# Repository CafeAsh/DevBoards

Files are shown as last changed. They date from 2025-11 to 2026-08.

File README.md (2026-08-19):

# Embedded Hardware Design Library

A collection of reusable embedded hardware designs developed as a personal reference library for future electronics and embedded-systems projects.

This repository contains custom development boards, microcontroller platforms, and DC-DC power-conversion designs. The goal is to maintain a structured library of proven circuit designs that can be reused, adapted, and expanded for future projects.

The designs emphasize **practical PCB implementation, component selection, power integrity, signal integrity, manufacturability, and reusable hardware architecture**.

This repository also serves as an ongoing engineering and learning platform. Designs are developed, evaluated, and refined to strengthen practical skills in embedded systems, PCB design, power electronics, signal integrity, and hardware validation. Lessons learned from each design are incorporated into subsequent revisions and projects.

---

## Repository Contents

### Microcontroller Development Boards

| Platform | MCU | Primary Focus |
| --- | --- | --- |
| ATtiny1616 | Microchip ATtiny1616 | Low-cost / low-power embedded control |
| ATmega32U4 | Microchip ATmega32U4 | USB-capable embedded applications |
| ESP32-S3 | Espressif ESP32-S3 | Wi-Fi / Bluetooth / high-performance embedded applications |
| RP2040 | Raspberry Pi RP2040 | Dual-core MCU development |
| STM32F103C8T6 | STMicroelectronics STM32F103C8T6 | ARM Cortex-M3 embedded development |

### Power Electronics

The repository also contains several DC-DC converter reference designs:

* Buck converter
* Boost converter
* SEPIC converter

These designs are intended as reusable starting points for future power-supply requirements, with component values and operating parameters selected for their respective target applications.

---

## Design Philosophy

The primary objective of this repository is **reusability**.

Rather than designing every development board or power stage from scratch, commonly used circuits are maintained as modular reference designs that can be incorporated into future projects.

Designs are developed with consideration for:

* Component availability
* PCB manufacturability
* Power distribution
* Decoupling and bypassing
* Signal integrity
* Grounding and return paths
* Programming and debugging interfaces
* Protection circuitry
* Ease of modification and reuse

---

## Development Boards

### ATtiny1616

Reference development board centered around the Microchip ATtiny1616 microcontroller.

Design considerations include:

* USB-to-serial conversion
* Programming/debug interface
* GPIO accessibility
* External power input
* Reset/programming provisions

### ATmega32U4

USB-capable development board based on the ATmega32U4.

The design provides a reusable platform for projects requiring:

* Native USB
* GPIO expansion
* Embedded control
* HID applications
* External peripherals

### ESP32-S3

Development platform based on the ESP32-S3 for projects requiring greater processing capability and wireless connectivity.

The design focuses on providing a reusable hardware platform while accounting for the additional power, RF, and high-speed considerations associated with the device.

### RP2040

Development board based on the Raspberry Pi RP2040.

The design provides a flexible platform for embedded applications requiring:

* Dual-core processing
* High-speed GPIO
* Programmable I/O
* USB connectivity
* External peripheral interfaces

### STM32F103C8T6

ARM Cortex-M3 development platform based on the STM32F103C8T6.

The design provides a compact reference platform for applications requiring:

* ARM Cortex-M development
* General-purpose peripherals
* Multiple communication interfaces
* External debugging/programming

---

## Power Conversion

### Buck Converter

Step-down DC-DC converter designs for applications requiring a regulated output voltage below the input voltage.

Design considerations include:

* Switching frequency
* Inductor selection
* Output capacitance
* MOSFET selection
* Diode or synchronous rectification
* Feedback network
* Switching losses
* Thermal performance
* PCB current paths

### Boost Converter

Step-up DC-DC converter designs for generating an output voltage greater than the input voltage.

Key considerations include:

* Inductor selection
* Switching device selection
* Diode characteristics
* Output ripple
* Duty-cycle limitations
* Feedback and regulation
* Current requirements

### SEPIC Converter

Single-Ended Primary-Inductor Converter designs for applications requiring an output voltage that may be either above or below the input voltage.

SEPIC designs are particularly useful when the input voltage can cross the desired output voltage while maintaining a non-inverting regulated output.

---

## Design Documentation

Each design is intended to become increasingly self-documenting as the repository develops.

Where applicable, documentation will include:

* Design objectives
* Electrical specifications
* Schematic
* PCB layout
* Bill of materials
* Component selection rationale
* Design calculations
* Simulation results
* PCB fabrication files
* Assembly information
* Bring-up and validation notes
* Known limitations
* Revision history

Measured results will be distinguished from simulated or calculated values.

---

## Tools

The designs in this repository may utilize:

* **KiCad** — Schematic capture and PCB design
* **LTspice** — Circuit simulation
* **Datasheet analysis** — Component selection and electrical verification
* **Embedded development tools** — Firmware development and hardware bring-up

Additional tools may be added as the library expands.

---

## Future Development

Planned additions and improvements include:

* Additional MCU development boards
* Expanded DC-DC converter library
* Reusable power-entry circuits
* USB interface designs
* Debug/programming interfaces
* ESD and transient protection circuits
* Load-switch and power-management circuits

---

## Status

This repository is an actively evolving engineering reference library.

Designs should be considered **development/reference hardware unless explicitly marked as validated**. Electrical specifications, component selections, and layouts may change as designs are tested and refined.

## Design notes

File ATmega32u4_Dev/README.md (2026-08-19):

# ATmega32U4 Development Board

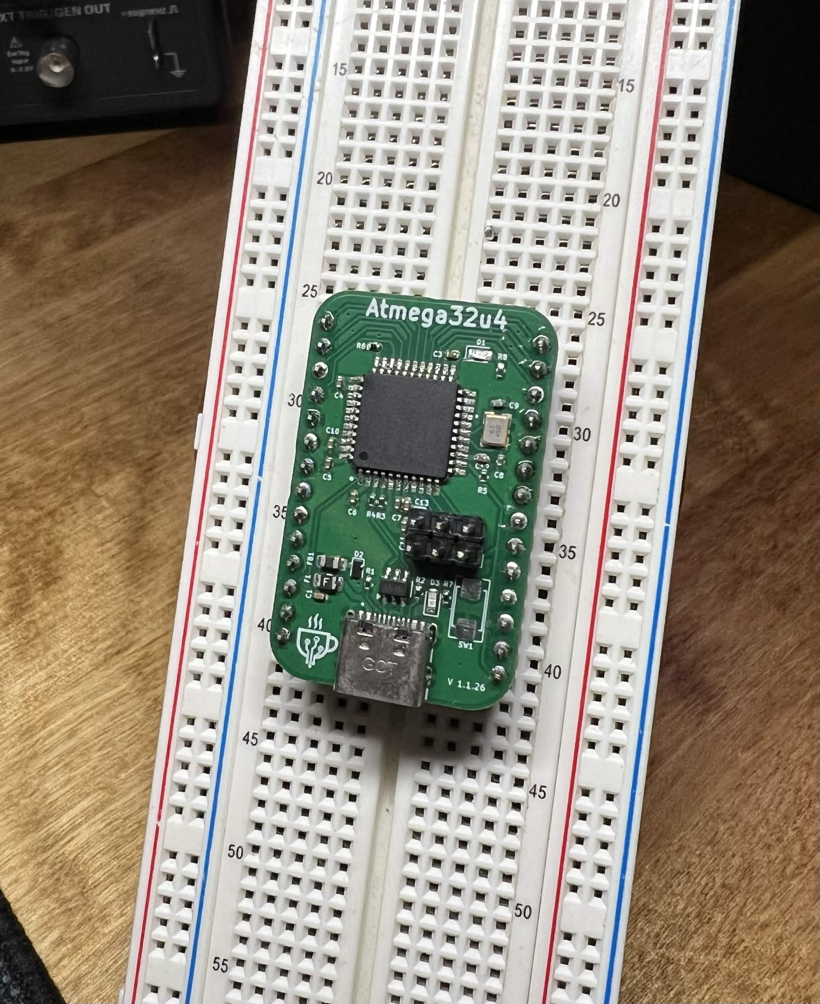
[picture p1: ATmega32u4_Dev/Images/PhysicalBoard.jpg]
Board


Development board based on the **ATmega32U4** microcontroller, designed for USB-enabled embedded projects, rapid prototyping, and firmware experimentation.

## Overview

This project provides a hardware platform built around the ATmega32U4, a microcontroller with native USB support.

Ideal use cases include:

* USB HID devices (keyboards, mice, gamepads)
* Serial communication over USB (CDC)
* Custom USB devices
* General embedded applications

## Features

* ATmega32U4 microcontroller
* Native USB support (no external USB-to-UART chip required)
* On-board 5V voltage regulation
* Power and Dataline surge protection
* ISP programming header
* Power Status LED
* Programable on board LED (Pin 13)
* GPIO breakout pins
* 16MHz Crystal Oscillator
* Designed to fit standard breadboards

## Microcontroller Details

* **Core:** AVR 8-bit
* **Flash Memory:** 32 KB
* **SRAM:** 2.5 KB
* **EEPROM:** 1 KB
* **Clock Speed:**  16 MHz
* **Interfaces:**
  * USB 2.0 Full Speed
  * UART
  * SPI
  * I2C (TWI)

## Pinout

*Pinout leaves some to be desired. Future re-works will better address pin layout*

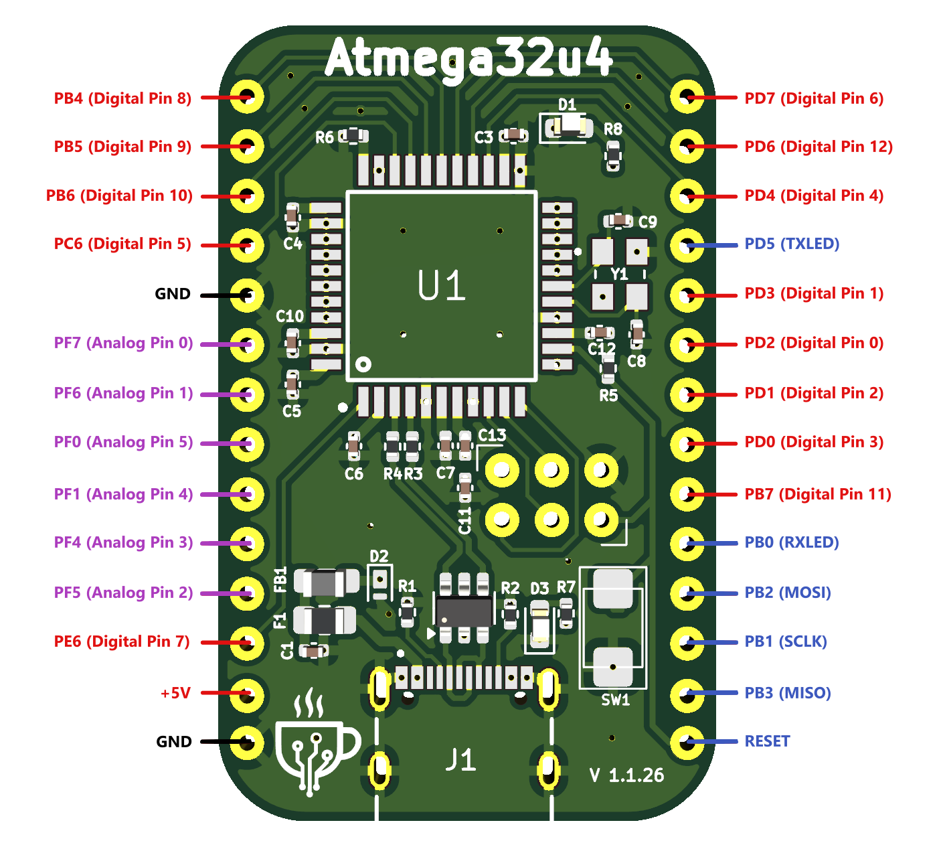
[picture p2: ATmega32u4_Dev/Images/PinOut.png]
Pinout


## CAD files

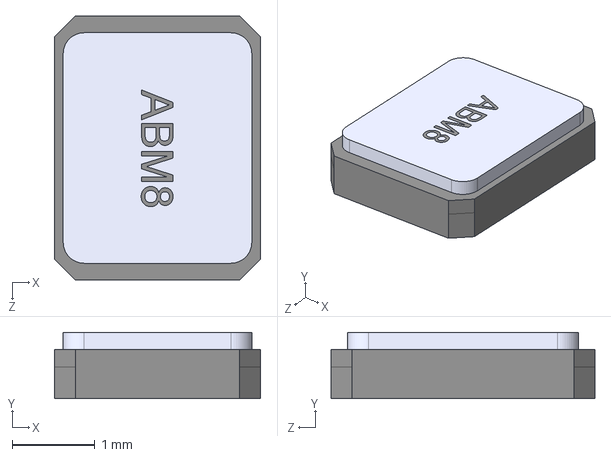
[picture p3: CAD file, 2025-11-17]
ATmega32u4_Dev 2-Layer/Models3/ABM8-16.000MHZ-10-1-U-T.step
2.50 x 0.8 x 3.20 mm

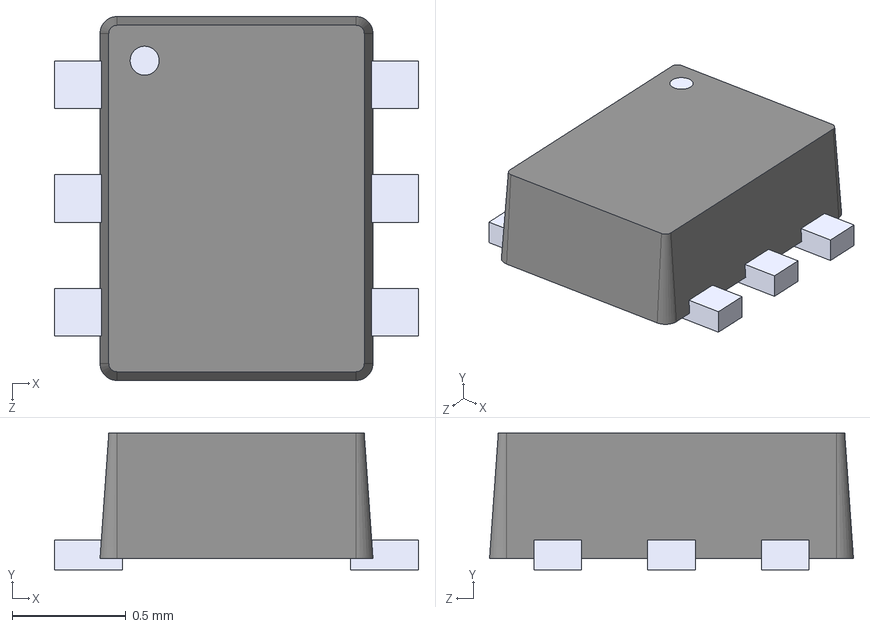
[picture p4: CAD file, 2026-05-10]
ESP32-S3_Dev/Model3/TPD2E1B06DRLR.step
1.60 x 0.6 x 1.60 mm

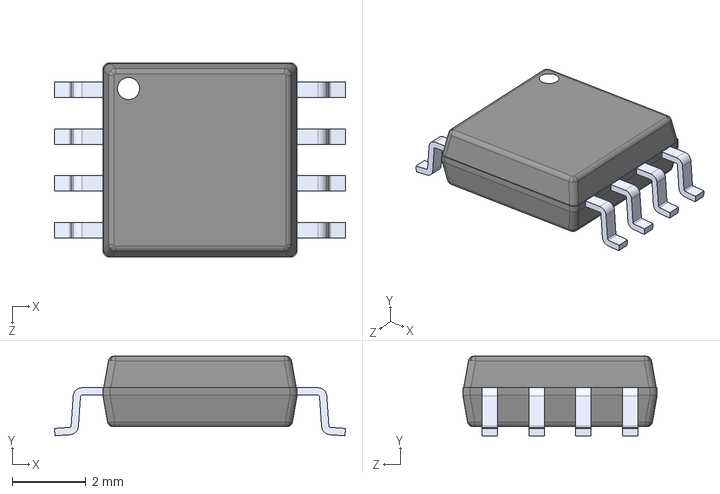
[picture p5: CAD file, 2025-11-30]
RP2040_Dev/Models3/W25Q128JVSIQ.step
7.90 x 2.16 x 5.28 mm

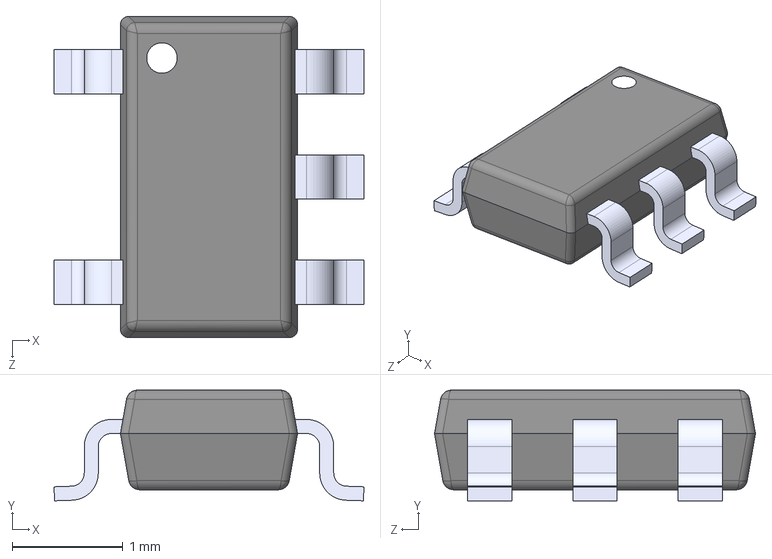
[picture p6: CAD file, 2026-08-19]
Voltage Conversion/Model3/MIC2288YD5-TR.step
2.80 x 1.00 x 2.90 mm

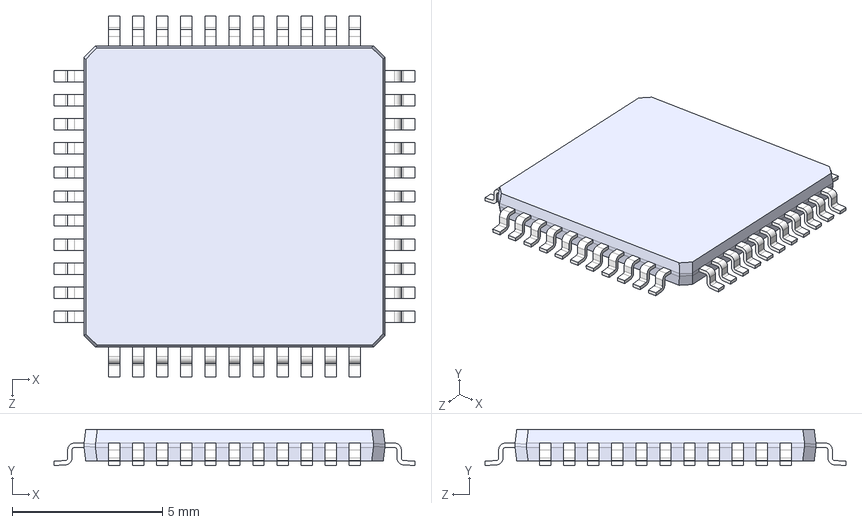
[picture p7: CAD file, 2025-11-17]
ATmega32u4_Dev 2-Layer/Models3/ATMEGA32U4-AU.step
12.0 x 1.20 x 12.0 mm

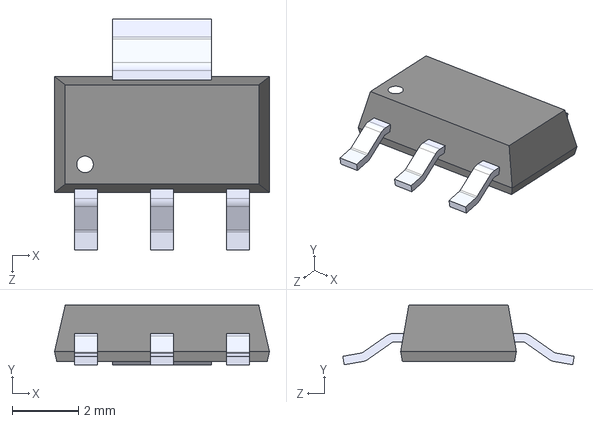
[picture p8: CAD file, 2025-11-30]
RP2040_Dev/Models3/LD1117S33TR.step
6.50 x 1.80 x 7.00 mm

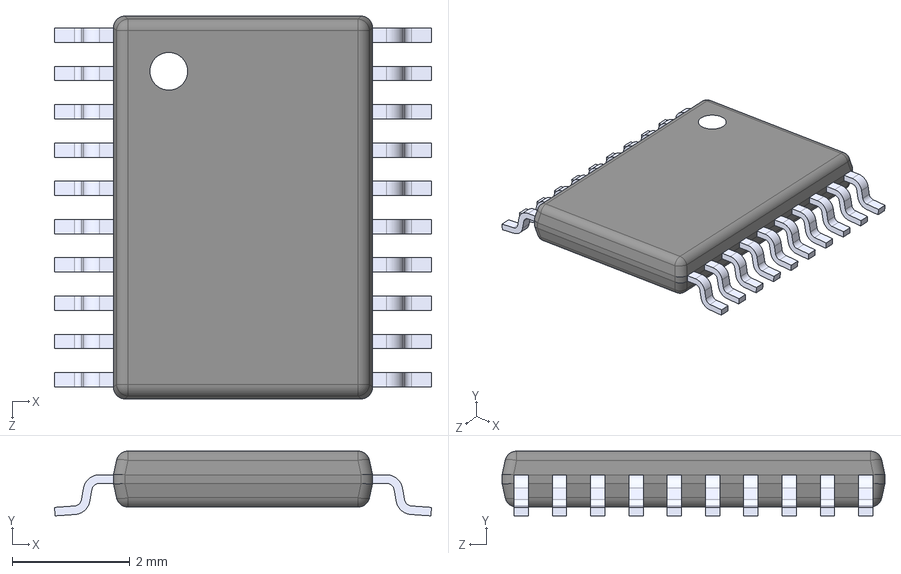
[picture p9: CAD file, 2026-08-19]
Voltage Conversion/Model3/LM5122MH_NOPB.step
6.40 x 1.10 x 6.50 mm

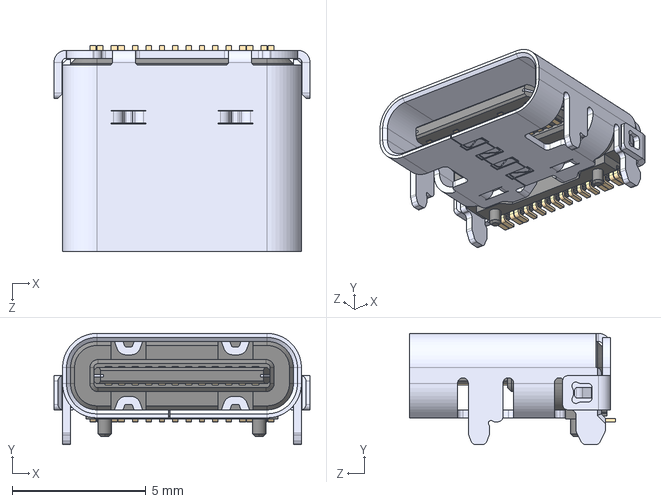
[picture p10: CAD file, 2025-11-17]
ATmega32u4_Dev 2-Layer/Models3/USB4105-GF-A.step
9.58 x 4.16 x 7.71 mm

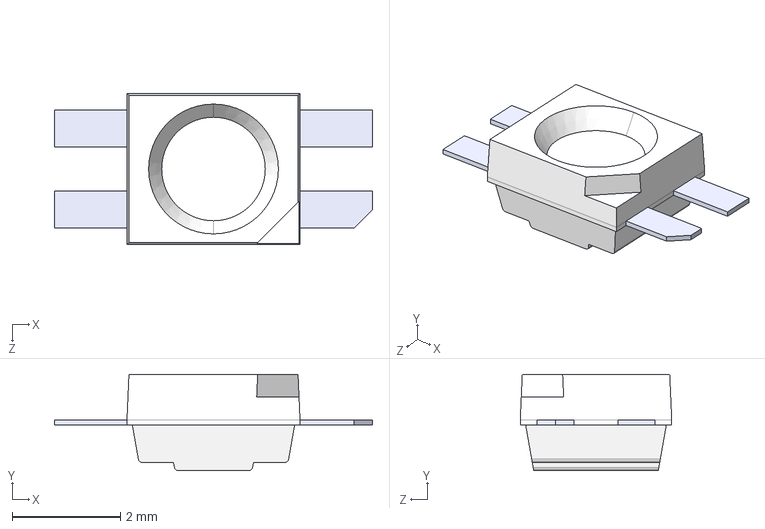
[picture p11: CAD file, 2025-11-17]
RP2040_Dev/Models3/SK6812-E.step
5.88 x 1.78 x 2.80 mm

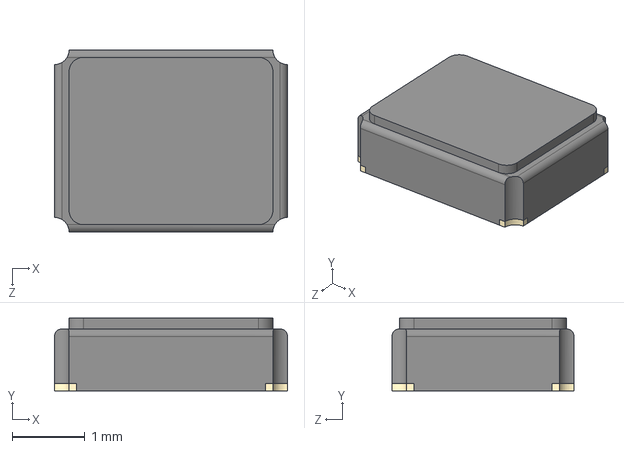
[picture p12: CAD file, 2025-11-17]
RP2040_Dev/Models3/ABM8G-12.000MHZ-4Y-T3.step
3.20 x 1.00 x 2.50 mm

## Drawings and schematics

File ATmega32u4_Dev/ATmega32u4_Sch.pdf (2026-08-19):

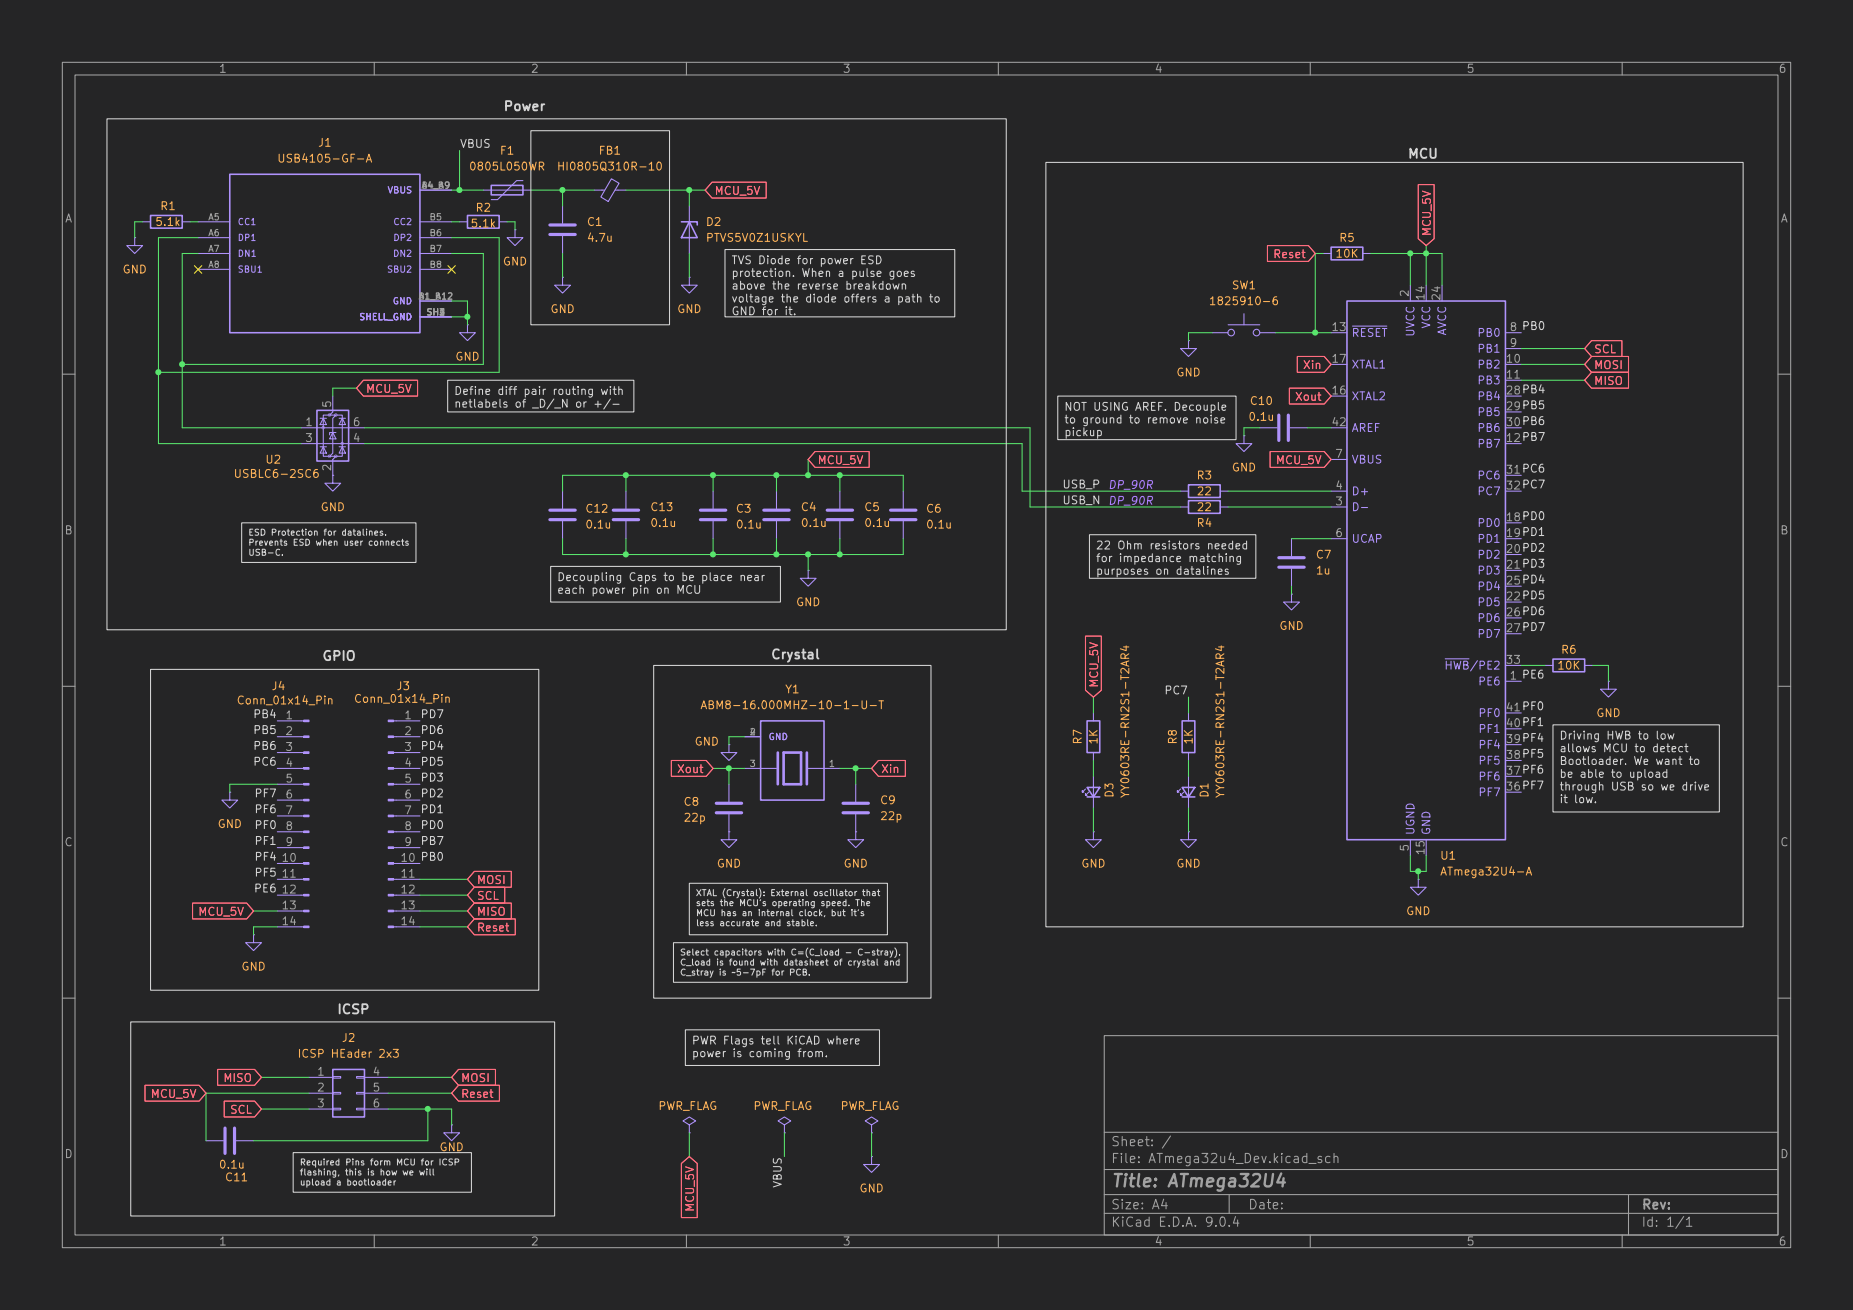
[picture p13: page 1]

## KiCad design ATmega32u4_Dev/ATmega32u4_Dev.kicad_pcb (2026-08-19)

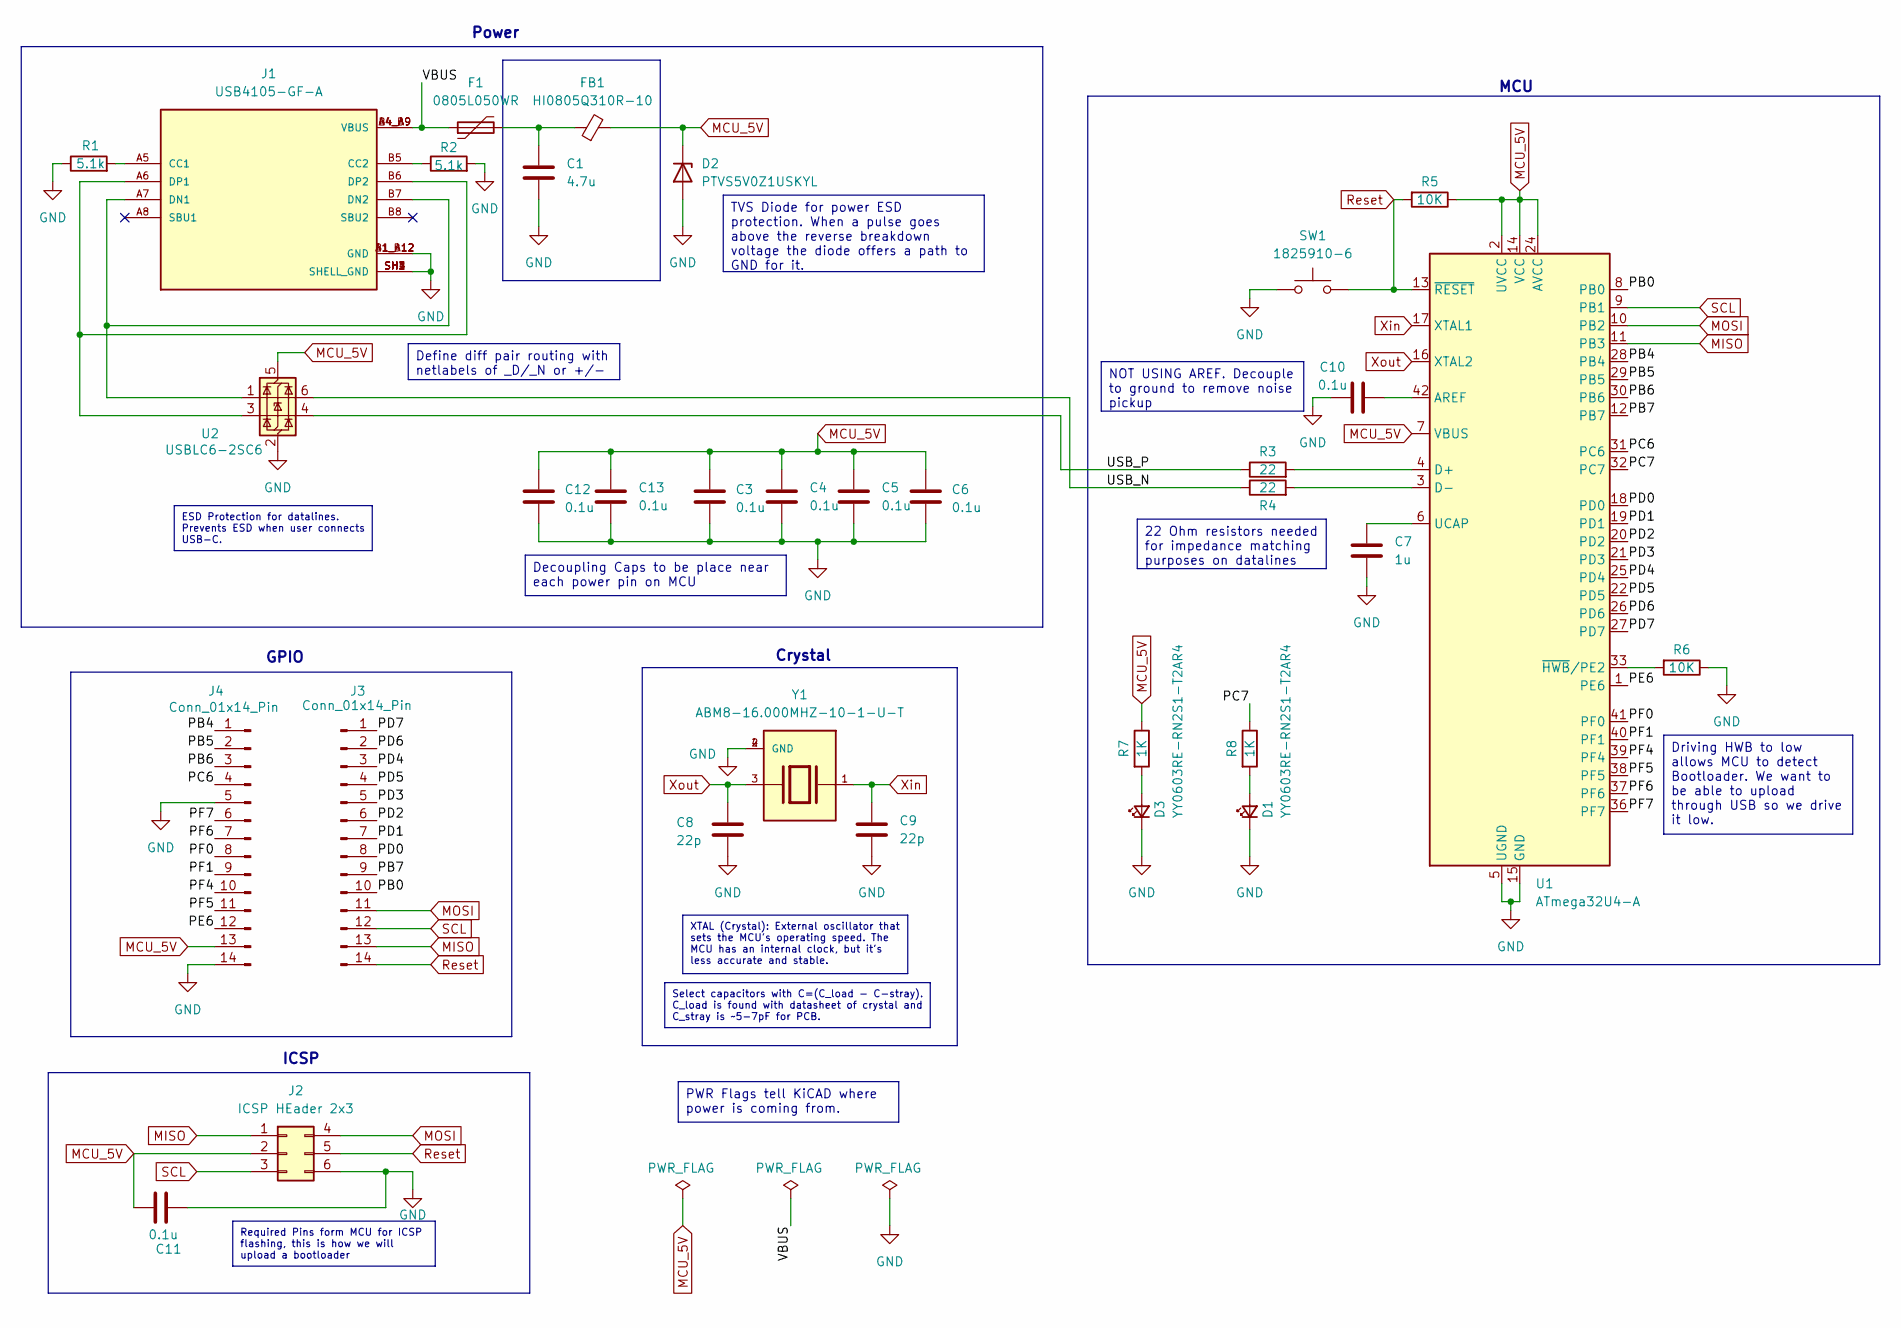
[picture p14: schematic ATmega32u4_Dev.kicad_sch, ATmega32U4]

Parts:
C1: 4.7u; C_0402_1005Metric
C3, C4, C5, C6, C10, C11, C12, C13: 0.1u; C_0402_1005Metric
C7: 1u; C_0402_1005Metric
C8, C9: 22p; C_0402_1005Metric
D1, D3: YY0603RE-RN2S1-T2AR4; LED_0603_1608Metric
D2: PTVS5V0Z1USKYL; Nexperia_DSN1608-2_1.6x0.8mm
F1: 0805L050WR; Fuse_0805_2012Metric_Pad1.15x1.40mm_HandSolder
FB1: HI0805Q310R-10; L_0805_2012Metric_Pad1.05x1.20mm_HandSolder
J1: USB4105-GF-A; GCT_USB4105-GF-A; PARTREV B4
J2: ICSP HEader 2x3; 02x03 Header
J3, J4: Conn_01x14_Pin; 01x14 Header (2.54 Pitch)
R1, R2: 5.1k; R_0402_1005Metric
R3, R4: 22; R_0402_1005Metric
R5, R6: 10K; R_0402_1005Metric
R7, R8: 1K; R_0402_1005Metric
SW1: 1825910-6; Generic SW 3x4mm
U1: ATmega32U4-A; QFP80P1200X1200X120-44N
U2: USBLC6-2SC6; SOT-23-6
Y1: ABM8-16.000MHZ-10-1-U-T; XTAL_ABM8-16.000MHZ-10-1-U-T; PARTREV 44041

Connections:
/PB0: J3.10, U1.8 (PB0)
/PB4: J4.1, U1.28 (PB4)
/PB5: J4.2, U1.29 (PB5)
/PB6: J4.3, U1.30 (PB6)
/PB7: J3.9, U1.12 (PB7)
/PC6: J4.4, U1.31 (PC6)
/PC7: R8.1, U1.32 (PC7)
/PD0: J3.8, U1.18 (PD0)
/PD1: J3.7, U1.19 (PD1)
/PD2: J3.6, U1.20 (PD2)
/PD3: J3.5, U1.21 (PD3)
/PD4: J3.3, U1.25 (PD4)
/PD5: J3.4, U1.22 (PD5)
/PD6: J3.2, U1.26 (PD6)
/PD7: J3.1, U1.27 (PD7)
/PE6: J4.12, U1.1 (PE6)
/PF0: J4.8, U1.41 (PF0)
/PF1: J4.9, U1.40 (PF1)
/PF4: J4.10, U1.39 (PF4)
/PF5: J4.11, U1.38 (PF5)
/PF6: J4.7, U1.37 (PF6)
/PF7: J4.6, U1.36 (PF7)
/USB_N: R4.1, U2.6 (I/O1)
/USB_P: R3.1, U2.4 (I/O2)
/VBUS: F1.1, J1.A4_B9 (VBUS), J1.B4_A9 (VBUS)
GND: C1.2, C3.2, C4.2, C5.2, C6.2, C7.2, C8.2, C9.2, C10.1, C11.2, C12.2, C13.2, D1.1 (K), D2.2 (A), D3.1 (K), J1.A1_B12 (GND), J1.B1_A12 (GND), J1.SH1 (SHELL_GND), J1.SH2 (SHELL_GND), J1.SH3 (SHELL_GND), J1.SH4 (SHELL_GND), J2.6, J4.5, J4.14, R1.1, R2.2, R6.1, SW1.1, U1.5 (UGND), U1.15 (GND), U1.23 (GND), U1.35 (GND), U1.43 (GND), U2.2 (GND), Y1.2 (GND), Y1.4 (GND)
MCU_5V: C3.1, C4.1, C5.1, C6.1, C11.1, C12.1, C13.1, D2.1 (K), FB1.2, J2.2, J4.13, R5.1, R7.1, U1.2 (UVCC), U1.7 (VBUS), U1.14 (VCC), U1.24 (AVCC), U1.34 (VCC), U1.44 (AVCC), U2.5 (VBUS)
MISO: J2.1, J3.13, U1.11 (PB3)
MOSI: J2.4, J3.11, U1.10 (PB2)
unnamed: C1.1, F1.2, FB1.1
unnamed: D1.2 (A), R8.2
unnamed: D3.2 (A), R7.2
unnamed: J1.A5 (CC1), R1.2
unnamed: J1.B5 (CC2), R2.1
unnamed: J1.A7 (DN1), J1.B7 (DN2), U2.1 (I/O1)
unnamed: J1.A6 (DP1), J1.B6 (DP2), U2.3 (I/O2)
unnamed: C10.2, U1.42 (AREF)
unnamed: R3.2, U1.4 (D+)
unnamed: R4.2, U1.3 (D-)
unnamed: C7.1, U1.6 (UCAP)
unnamed: R6.2, U1.33 (~HWB/PE2)
Reset: J2.5, J3.14, R5.2, SW1.2, U1.13 (~RESET)
SCL: J2.3, J3.12, U1.9 (PB1)
Xin: C9.1, U1.17 (XTAL1), Y1.1
Xout: C8.1, U1.16 (XTAL2), Y1.3

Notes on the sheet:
MCU
GPIO
Crystal
ICSP
Power
Driving HWB to low allows MCU to detect Bootloader. We want to be able to upload through USB so we drive it low.
NOT USING AREF. Decouple to ground to remove noise pickup
PWR Flags tell KiCAD where power is coming from.
ESD Protection for datalines. Prevents ESD when user connects USB-C.
TVS Diode for power ESD protection. When a pulse goes above the reverse breakdown voltage the diode offers a path to GND for it.
22 Ohm resistors needed for impedance matching purposes on datalines
Required Pins form MCU for ICSP flashing, this is how we will upload a bootloader
Decoupling Caps to be place near each power pin on MCU
XTAL (Crystal): External oscillator that sets the MCU's operating speed. The MCU has an internal clock, but it's less accurate and stable.
Select capacitors with C=(C_load - C-stray). C_load is found with datasheet of crystal and C_stray is ~5-7pF for PCB.
Define diff pair routing with netlabels of _D/_N or +/-

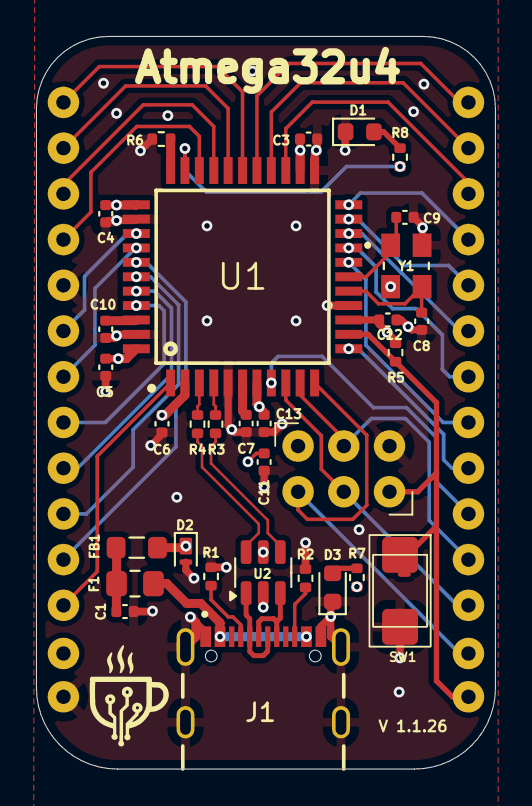
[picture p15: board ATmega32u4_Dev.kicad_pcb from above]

Board: 4 copper layers, 25.5 x 40.7 mm, 33 parts (0 on the bottom side), 45 nets.

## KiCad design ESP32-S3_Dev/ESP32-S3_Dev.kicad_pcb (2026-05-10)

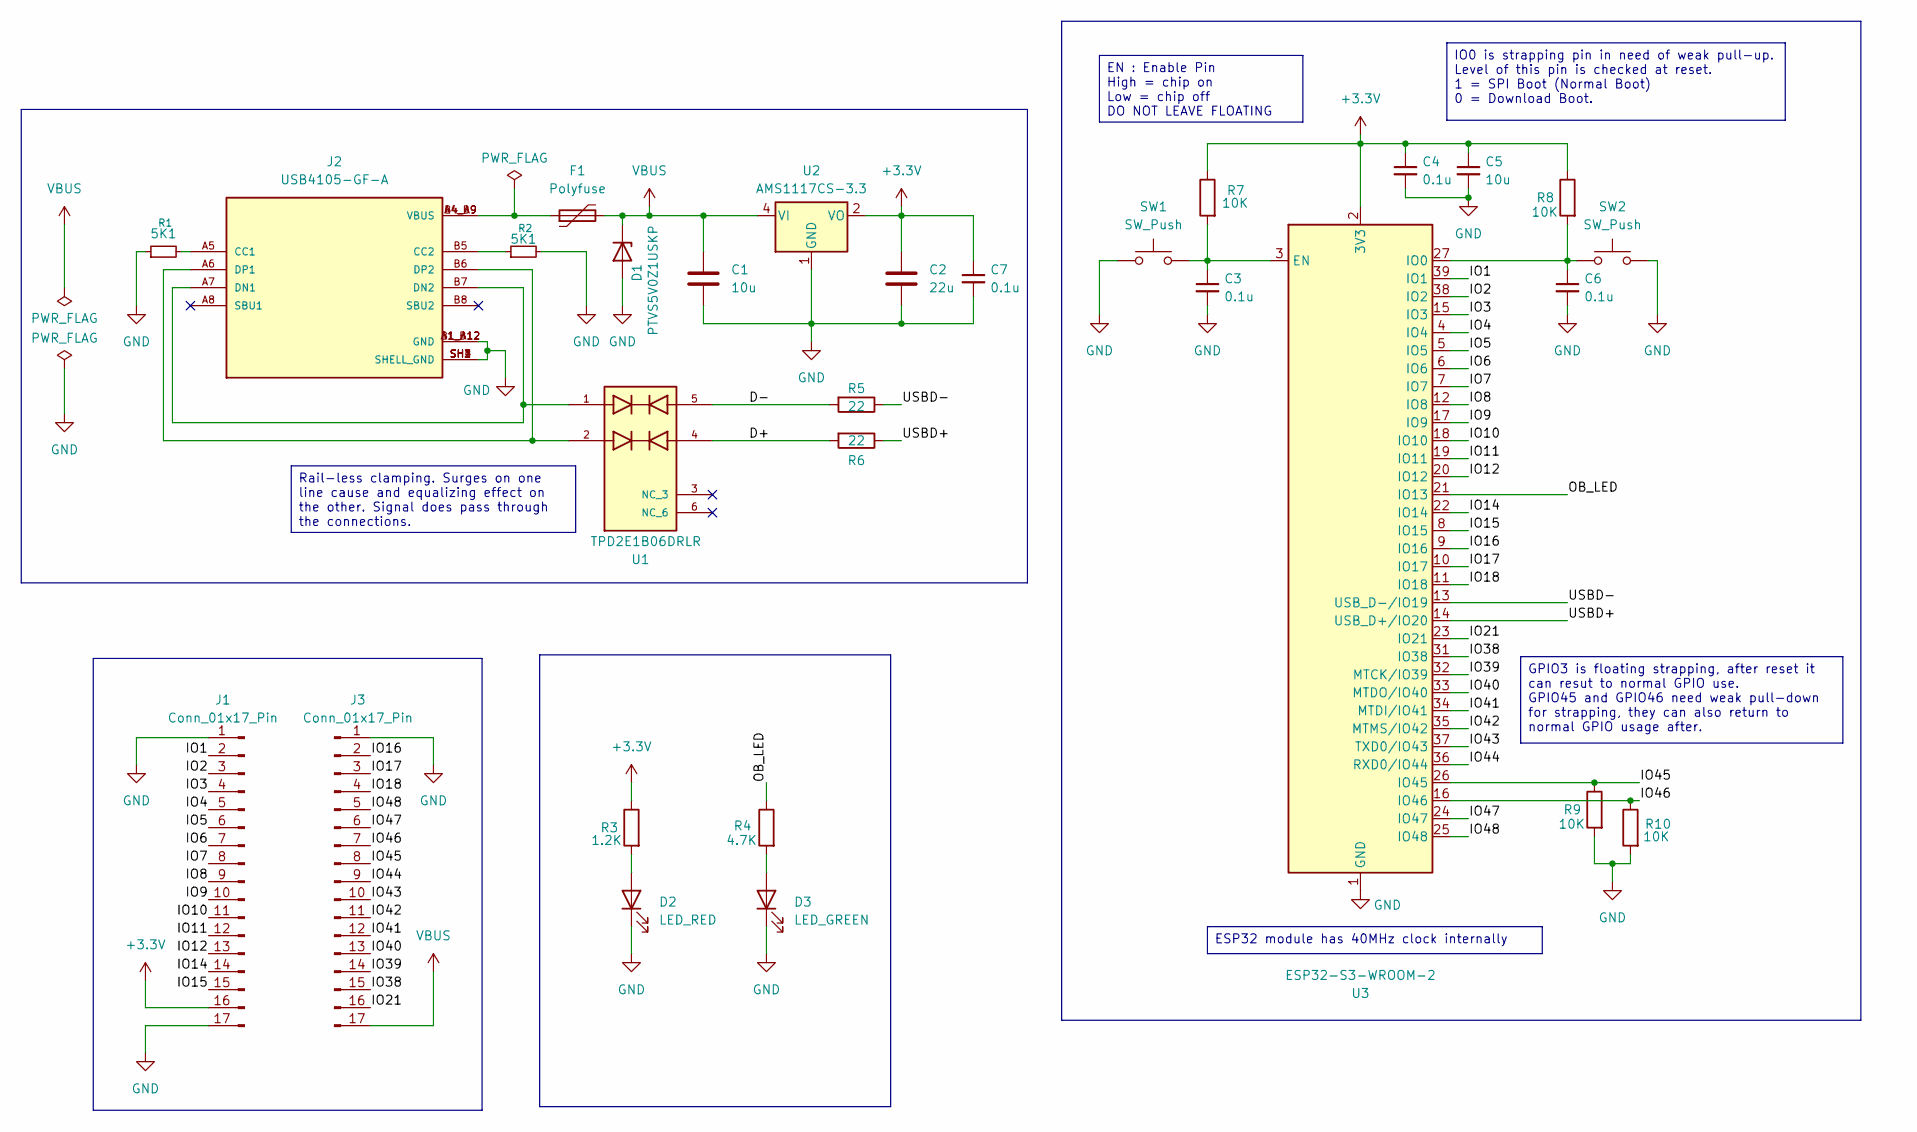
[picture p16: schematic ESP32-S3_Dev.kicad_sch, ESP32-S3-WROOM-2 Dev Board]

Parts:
C1, C5: 10u; C_0402_1005Metric
C2: 22u; C_0402_1005Metric
C3, C4, C6, C7: 0.1u; C_0402_1005Metric
D1: PTVS5V0Z1USKP; Nexperia_DSN1608-2_1.6x0.8mm
D2: LED_RED; LED_0603_1608Metric
D3: LED_GREEN; LED_0603_1608Metric
F1: Polyfuse; Fuse_0603_1608Metric
J1, J3: Conn_01x17_Pin; PinHeader_1x17_P2.54mm_Vertical
J2: USB4105-GF-A; USB_C_Receptacle_GCT_USB4105-xx-A_16P_TopMnt_Horizontal; PARTREV B4
R1, R2: 5K1; R_0402_1005Metric
R3: 1.2K; R_0402_1005Metric
R4: 4.7K; R_0402_1005Metric
R5, R6: 22; R_0402_1005Metric
R7, R8, R9, R10: 10K; R_0402_1005Metric
SW1, SW2: SW_Push; R_0402_1005Metric
U1: TPD2E1B06DRLR; SOTFL50P160X60-6N; PARTREV D
U2: AMS1117CS-3.3; SOIC-8_3.9x4.9mm_P1.27mm
U3: ESP32-S3-WROOM-2

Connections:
+3.3V: C2.1, C4.1, C5.1, C7.1, J1.16, R3.1, R7.1, R8.1, U2.2 (VO), U2.3 (VO), U2.6 (VO), U2.7 (VO), U3.2 (3V3)
/D+: R6.2, U1.4
/D-: R5.2, U1.5
/IO1: J1.2, U3.39 (IO1)
/IO2: J1.3, U3.38 (IO2)
/IO3: J1.4, U3.15 (IO3)
/IO4: J1.5, U3.4 (IO4)
/IO5: J1.6, U3.5 (IO5)
/IO6: J1.7, U3.6 (IO6)
/IO7: J1.8, U3.7 (IO7)
/IO8: J1.9, U3.12 (IO8)
/IO9: J1.10, U3.17 (IO9)
/IO10: J1.11, U3.18 (IO10)
/IO11: J1.12, U3.19 (IO11)
/IO12: J1.13, U3.20 (IO12)
/IO14: J1.14, U3.22 (IO14)
/IO15: J1.15, U3.8 (IO15)
/IO16: J3.2, U3.9 (IO16)
/IO17: J3.3, U3.10 (IO17)
/IO18: J3.4, U3.11 (IO18)
/IO21: J3.16, U3.23 (IO21)
/IO38: J3.15, U3.31 (IO38)
/IO39: J3.14, U3.32 (MTCK/IO39)
/IO40: J3.13, U3.33 (MTDO/IO40)
/IO41: J3.12, U3.34 (MTDI/IO41)
/IO42: J3.11, U3.35 (MTMS/IO42)
/IO43: J3.10, U3.37 (TXD0/IO43)
/IO44: J3.9, U3.36 (RXD0/IO44)
/IO45: J3.8, R9.1, U3.26 (IO45)
/IO46: J3.7, R10.1, U3.16 (IO46)
/IO47: J3.6, U3.24 (IO47)
/IO48: J3.5, U3.25 (IO48)
/OB_LED: R4.1, U3.21 (IO13)
/USBD+: R6.1, U3.14 (USB_D+/IO20)
/USBD-: R5.1, U3.13 (USB_D-/IO19)
GND: C1.2, C2.2, C3.2, C4.2, C5.2, C6.2, C7.2, D1.2 (A), D2.1 (K), D3.1 (K), J1.1, J1.17, J2.A1_B12 (GND), J2.B1_A12 (GND), J2.SH1 (SHELL_GND), J2.SH2 (SHELL_GND), J2.SH3 (SHELL_GND), J2.SH4 (SHELL_GND), J3.1, R1.1, R2.2, R9.2, R10.2, SW1.1, SW2.2, U2.1 (GND), U3.1 (GND), U3.40 (GND), U3.41 (GND)
unnamed: D2.2 (A), R3.2
unnamed: D3.2 (A), R4.2
unnamed: F1.1, J2.A4_B9 (VBUS), J2.B4_A9 (VBUS)
unnamed: J2.A5 (CC1), R1.2
unnamed: J2.B5 (CC2), R2.1
unnamed: J2.A7 (DN1), J2.B7 (DN2), U1.1
unnamed: J2.A6 (DP1), J2.B6 (DP2), U1.2
unnamed: C3.1, R7.2, SW1.2, U3.3 (EN)
unnamed: C6.1, R8.2, SW2.1, U3.27 (IO0)
VBUS: C1.1, D1.1 (K), F1.2, J3.17, U2.4 (VI)

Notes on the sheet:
Rail-less clamping. Surges on one line cause and equalizing effect on the other. Signal does pass through the connections.
EN : Enable Pin High = chip on Low = chip off DO NOT LEAVE FLOATING
GPIO3 is floating strapping, after reset it can resut to normal GPIO use. GPIO45 and GPIO46 need weak pull-down for strapping, they can also return to normal GPIO usage after.
ESP32 module has 40MHz clock internally
IO0 is strapping pin in need of weak pull-up. Level of this pin is checked at reset. 1 = SPI Boot (Normal Boot) 0 = Download Boot.

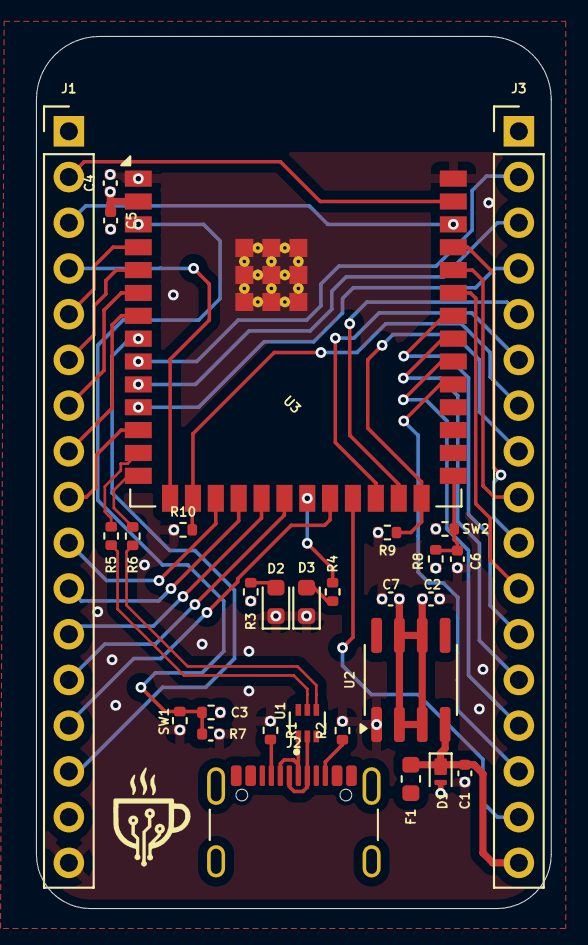
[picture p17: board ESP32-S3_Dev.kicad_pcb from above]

Board: 4 copper layers, 28.6 x 48.5 mm, 29 parts (0 on the bottom side), 45 nets.

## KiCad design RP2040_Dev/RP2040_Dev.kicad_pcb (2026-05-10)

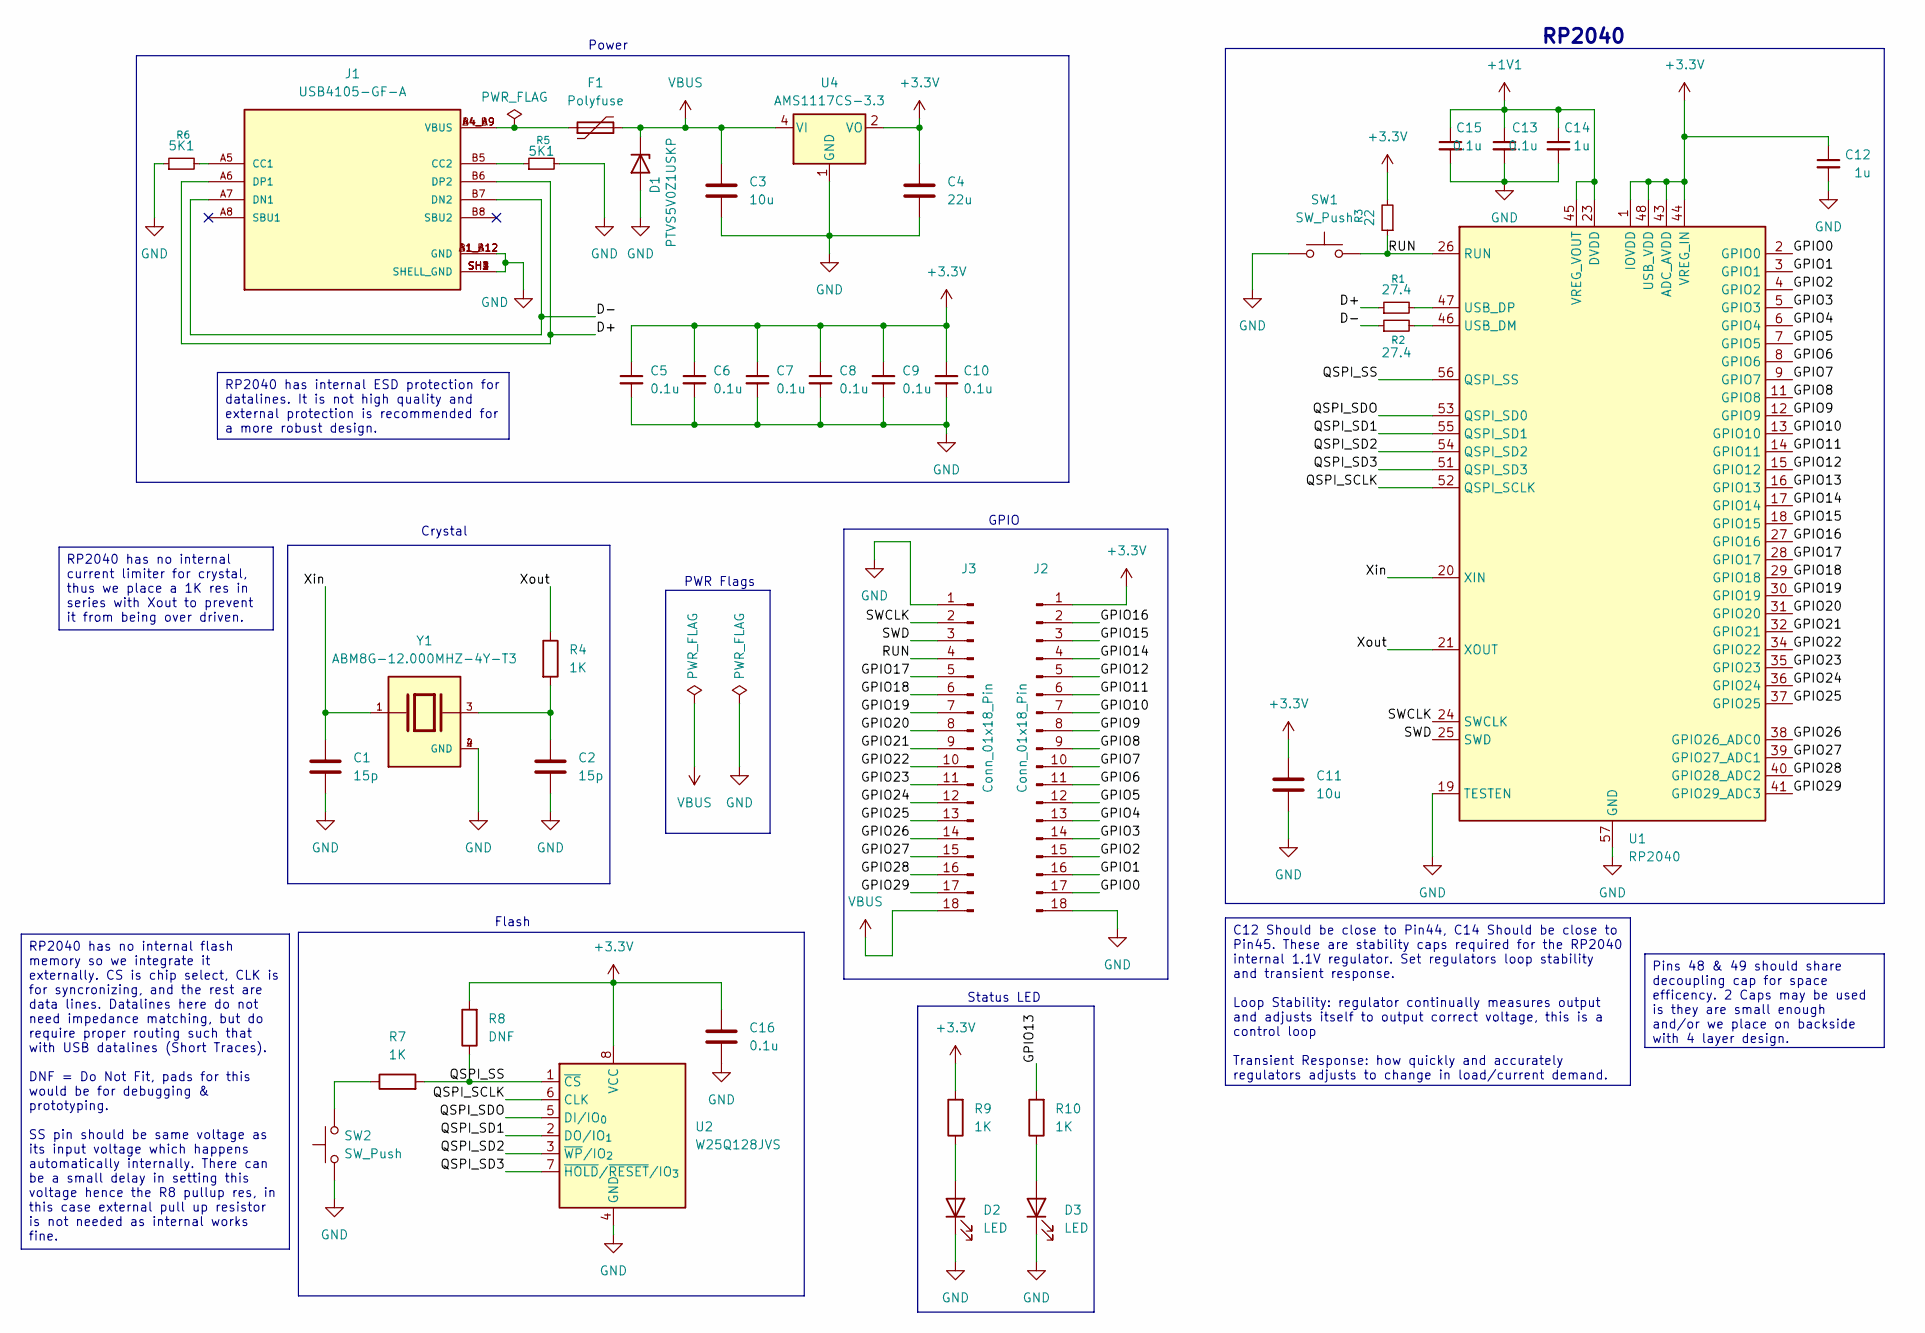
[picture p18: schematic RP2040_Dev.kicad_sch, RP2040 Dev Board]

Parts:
C1, C2: 15p; C_0402_1005Metric
C3, C11: 10u; C_0402_1005Metric
C4: 22u; C_0402_1005Metric
C5, C6, C7, C8, C9, C10, C13, C15, C16: 0.1u; C_0402_1005Metric
C12, C14: 1u; C_0402_1005Metric
D1: PTVS5V0Z1USKP; Nexperia_DSN1608-2_1.6x0.8mm
D2, D3: LED; LED_0603_1608Metric_Pad1.05x0.95mm_HandSolder
F1: Polyfuse; Fuse_0603_1608Metric
J1: USB4105-GF-A; GCT_USB4105-GF-A; PARTREV B4
J2, J3: Conn_01x18_Pin; PinHeader_1x18_P2.54mm_Vertical
R1, R2: 27.4; R_0201_0603Metric_Pad0.64x0.40mm_HandSolder
R3: 22; R_0201_0603Metric_Pad0.64x0.40mm_HandSolder
R4: 1K; R_0201_0603Metric_Pad0.64x0.40mm_HandSolder
R5, R6: 5K1; R_0201_0603Metric_Pad0.64x0.40mm_HandSolder
R7, R9, R10: 1K; R_0402_1005Metric
R8: DNF; R_0402_1005Metric
SW1, SW2: SW_Push; L_0805_2012Metric_Pad1.05x1.20mm_HandSolder
U1: RP2040; QFN-56-1EP_7x7mm_P0.4mm_EP3.2x3.2mm
U2: W25Q128JVS; SOIC-8_5.3x5.3mm_P1.27mm
U4: AMS1117CS-3.3; SOIC-8_3.9x4.9mm_P1.27mm
Y1: ABM8G-12.000MHZ-4Y-T3; XTAL_ABM8G-12.000MHZ-4Y-T3; PARTREV 08.13.15

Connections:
+1V1: C13.1, C14.1, C15.1, U1.23 (DVDD), U1.45 (VREG_VOUT), U1.50 (DVDD)
+3.3V: C4.1, C5.1, C6.1, C7.1, C8.1, C9.1, C10.1, C11.1, C12.1, C16.1, J2.1, R3.2, R8.2, R9.2, U1.1 (IOVDD), U1.10 (IOVDD), U1.22 (IOVDD), U1.33 (IOVDD), U1.42 (IOVDD), U1.43 (ADC_AVDD), U1.44 (VREG_IN), U1.48 (USB_VDD), U1.49 (IOVDD), U2.8 (VCC), U4.2 (VO), U4.3 (VO), U4.6 (VO), U4.7 (VO)
/D+: J1.A6 (DP1), J1.B6 (DP2), R1.1
/D-: J1.A7 (DN1), J1.B7 (DN2), R2.1
/GPIO0: J2.17, U1.2 (GPIO0)
/GPIO1: J2.16, U1.3 (GPIO1)
/GPIO2: J2.15, U1.4 (GPIO2)
/GPIO3: J2.14, U1.5 (GPIO3)
/GPIO4: J2.13, U1.6 (GPIO4)
/GPIO5: J2.12, U1.7 (GPIO5)
/GPIO6: J2.11, U1.8 (GPIO6)
/GPIO7: J2.10, U1.9 (GPIO7)
/GPIO8: J2.9, U1.11 (GPIO8)
/GPIO9: J2.8, U1.12 (GPIO9)
/GPIO10: J2.7, U1.13 (GPIO10)
/GPIO11: J2.6, U1.14 (GPIO11)
/GPIO12: J2.5, U1.15 (GPIO12)
/GPIO13: R10.2, U1.16 (GPIO13)
/GPIO14: J2.4, U1.17 (GPIO14)
/GPIO15: J2.3, U1.18 (GPIO15)
/GPIO16: J2.2, U1.27 (GPIO16)
/GPIO17: J3.5, U1.28 (GPIO17)
/GPIO18: J3.6, U1.29 (GPIO18)
/GPIO19: J3.7, U1.30 (GPIO19)
/GPIO20: J3.8, U1.31 (GPIO20)
/GPIO21: J3.9, U1.32 (GPIO21)
/GPIO22: J3.10, U1.34 (GPIO22)
/GPIO23: J3.11, U1.35 (GPIO23)
/GPIO24: J3.12, U1.36 (GPIO24)
/GPIO25: J3.13, U1.37 (GPIO25)
/GPIO26: J3.14, U1.38 (GPIO26_ADC0)
/GPIO27: J3.15, U1.39 (GPIO27_ADC1)
/GPIO28: J3.16, U1.40 (GPIO28_ADC2)
/GPIO29: J3.17, U1.41 (GPIO29_ADC3)
/QSPI_SCLK: U1.52 (QSPI_SCLK), U2.6 (CLK)
/QSPI_SD1: U1.55 (QSPI_SD1), U2.2 (DO/IO_{1})
/QSPI_SD2: U1.54 (QSPI_SD2), U2.3 (~WP/IO_{2})
/QSPI_SD3: U1.51 (QSPI_SD3), U2.7 (~HOLD/~RESET/IO_{3})
/QSPI_SDO: U1.53 (QSPI_SD0), U2.5 (DI/IO_{0})
/QSPI_SS: R7.2, R8.1, U1.56 (QSPI_SS), U2.1 (~CS)
/RUN: J3.4, R3.1, SW1.2, U1.26 (RUN)
/SWCLK: J3.2, U1.24 (SWCLK)
/SWD: J3.3, U1.25 (SWD)
/Xin: C1.1, U1.20 (XIN), Y1.1
/Xout: R4.1, U1.21 (XOUT)
GND: C1.2, C2.2, C3.2, C4.2, C5.2, C6.2, C7.2, C8.2, C9.2, C10.2, C11.2, C12.2, C13.2, C14.2, C15.2, C16.2, D1.2 (A), D2.1 (K), D3.1 (K), J1.A1_B12 (GND), J1.B1_A12 (GND), J1.SH1 (SHELL_GND), J1.SH2 (SHELL_GND), J1.SH3 (SHELL_GND), J1.SH4 (SHELL_GND), J2.18, J3.1, R5.2, R6.1, SW1.1, SW2.1, U1.19 (TESTEN), U1.57 (GND), U2.4 (GND), U4.1 (GND), Y1.2 (GND), Y1.4 (GND)
unnamed: C2.1, R4.2, Y1.3
unnamed: D2.2 (A), R9.1
unnamed: D3.2 (A), R10.1
unnamed: F1.1, J1.A4_B9 (VBUS), J1.B4_A9 (VBUS)
unnamed: J1.A5 (CC1), R6.2
unnamed: J1.B5 (CC2), R5.1
unnamed: R7.1, SW2.2
unnamed: R2.2, U1.46 (USB_DM)
unnamed: R1.2, U1.47 (USB_DP)
VBUS: C3.1, D1.1 (K), F1.2, J3.18, U4.4 (VI)

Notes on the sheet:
Crystal
GPIO
Status LED
RP2040
Flash
Power
PWR Flags
RP2040 has no internal flash memory so we integrate it externally. CS is chip select, CLK is for syncronizing, and the rest are data lines. Datalines here do not need impedance matching, but do require proper routing such that with USB datalines (Short Traces). DNF = Do Not Fit, pads for this would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
RP2040 has internal ESD protection for datalines. It is not high quality and external protection is recommended for a more robust design.
C12 Should be close to Pin44, C14 Should be close to Pin45. These are stability caps required for the RP2040 internal 1.1V regulator. Set regulators loop stability and transient response. Loop Stability: regulator continually measures output and adjusts itself to output correct voltage, this is a c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
Pins 48 & 49 should share decoupling cap for space efficency. 2 Caps may be used is they are small enough and/or we place on backside with 4 layer design.
RP2040 has no internal current limiter for crystal, thus we place a 1K res in series with Xout to prevent it from being over driven.

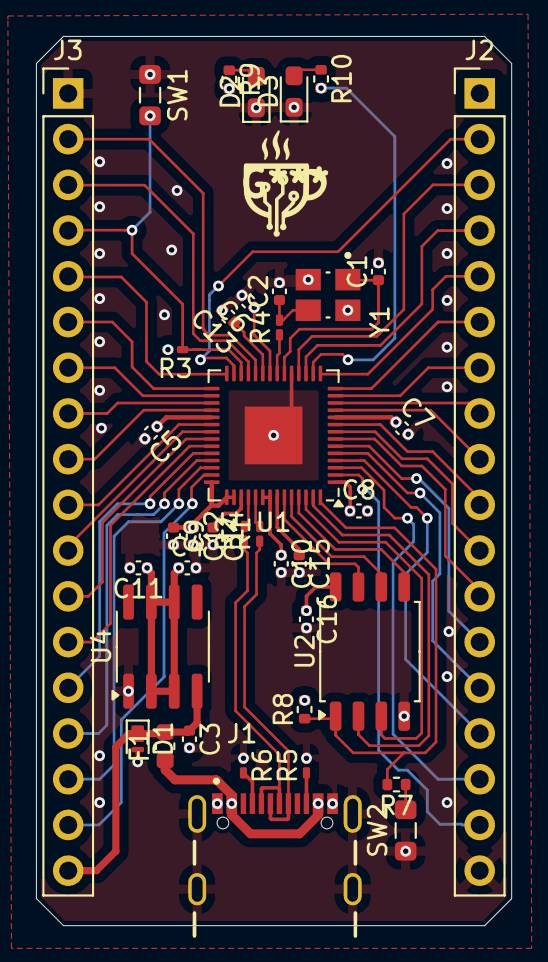
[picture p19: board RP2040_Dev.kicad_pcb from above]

Board: 4 copper layers, 26.4 x 49.4 mm, 39 parts (0 on the bottom side), 56 nets.

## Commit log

2025-11-17 intitial commit
    [ABM8-16.000MHZ-10-1-U-T.step, ABM8G-12.000MHZ-4Y-T3.step, ATMEGA32U4-AU.step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]
2025-11-18 changed GPIO
    [ATmega32u4_Dev.kicad_pcb, ATmega32u4_Dev.kicad_sch]
2025-11-19 Adjusted Layout
    [ATmega32u4_Dev.kicad_pcb, ATmega32u4_Dev.kicad_sch]
2025-11-30 4-layer Atmega and RP2040
    [ABM8-16.000MHZ-10-1-U-T.step, ABM8G-12.000MHZ-4Y-T3.step, ATMEGA32U4-AU.step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]
2025-12-04 rp2040 update
    [RP2040_Dev.kicad_pcb, RP2040_Dev.kicad_sch]
2025-12-09 Final Atmega32u4
    [ABM8G-12.000MHZ-4Y-T3.step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]
2025-12-31 Adjusted Headers on ATmega32
    [ABM8-16.000MHZ-10-1-U-T.step, ABM8G-12.000MHZ-4Y-T3.step, ATMEGA32U4-AU.step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]
2026-04-13 Cleaned up atmega and made atmega32 README
    [ABM8-16.000MHZ-10-1-U-T.step, ATMEGA32U4-AU.step, ATmega32u4_Dev.kicad_pcb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]
2026-05-10 Added additional board folders, updataed RP2040, ATmega, and ESP32
    [ATiny1616_Dev.kicad_pcb, ATiny1616_Dev.kicad_sch, ATmega32u4_Dev.kicad_pcb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]
2026-05-18 Some changes to attiny
    [ATiny1616_Dev.kicad_sch]
2026-05-29 Voltage Converters
    [Voltage Conversion.kicad_sch]
2026-08-19 Adjustments to ATmega32, README files, Added SEPIC converter to voltage converters, General progress on other designs
    [ATmega32u4_Dev.kicad_pcb, ATmega32u4_Dev.kicad_sch, Boost.kicad_sch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]
